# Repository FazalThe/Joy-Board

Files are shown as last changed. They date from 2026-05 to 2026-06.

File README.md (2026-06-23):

# Joy Board

A custom-built split keyboard with a built in thumb joystick on the left side, runs on zmk firmware and also supports zmk studio. The joystick is inteded to use the movements as key presses, but later is when I realised that it's really good for gaming( I don't really game, maybe thats why).

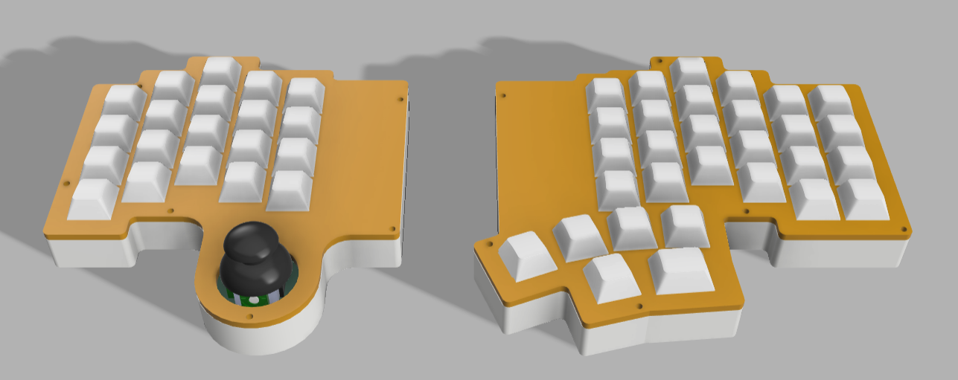
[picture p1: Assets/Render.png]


---

##  Features

-  Split Ergonomic Layout
- Thumb Joystick (Left Side)
- ZMK Studio 

---

## Schematic

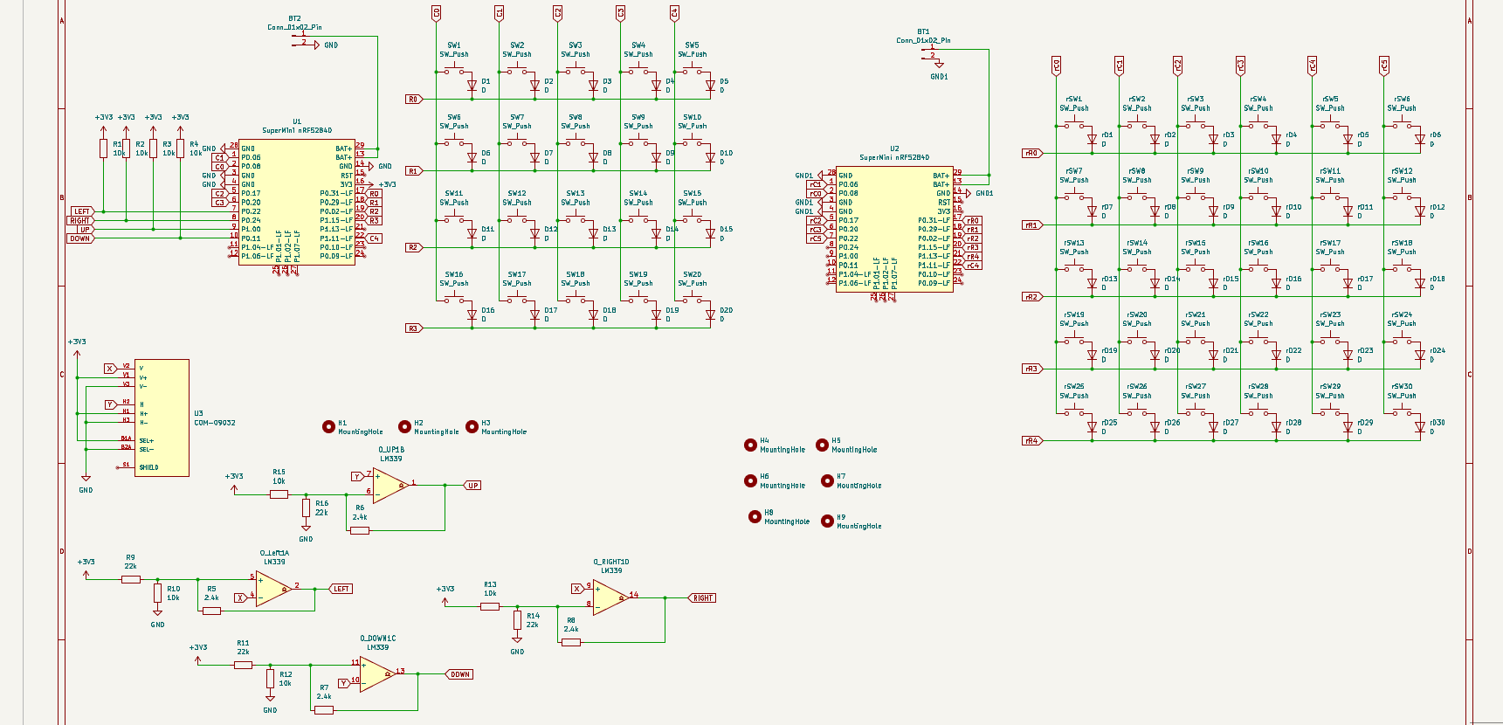
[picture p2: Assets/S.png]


---

##  PCB 

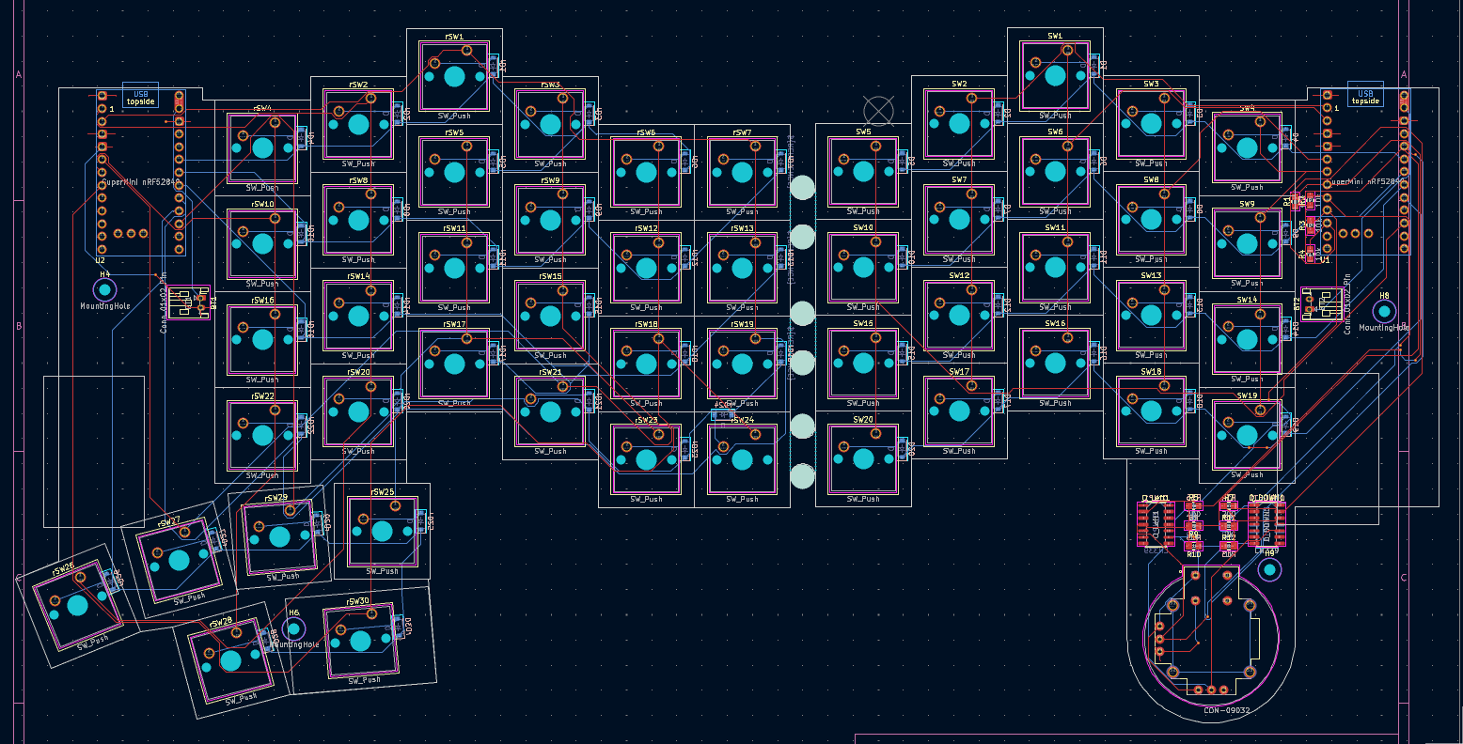
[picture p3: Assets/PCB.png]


---

## Case

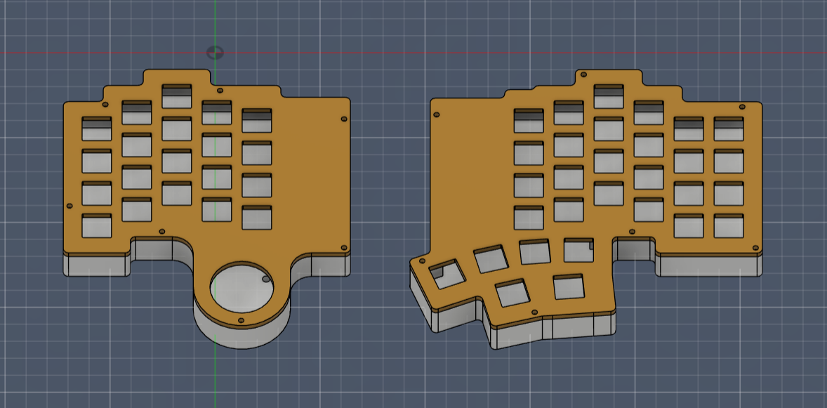
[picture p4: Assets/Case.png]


## BOM
- 2x Pro Micro nRF52840
- 50 x 1N5819 SMD Diodes
- 50 x MX-Style switches (and keycaps)
- 1  x COM-09032
- 2  x JST PH 2pin
- 8  x 10k ohm 0805 resistor
- 4  x 22k ohm 0805 resistor
- 4  x 2.4k ohm 0805 resistor
- 4  x LM339 - SOIC14
- 2  x 100-400 MaH li-po battery
- 4  x 4mm M2 Heatset insert
- 14 x 6mm M2 Heatset insert
- 4  x 6mm M2 Screws
- 14 x 8mm M2 Screws

---

## Credits

- Cherry MX keycap 3D model from [GrabCAD](https://grabcad.com/library/cherry-mx-keycaps-1).

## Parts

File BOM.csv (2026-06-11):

name | price | quantity | link | total |  | delivery and tax | whole total | USD
Cherry_MX_1u_PCB_Switch | 180 | 10 | https://stackskb.com/store/click-inc-hp-switch-pack-of-10-pre-order/ | 900
1N4148_SOD123_Diode | 20 | 5 | https://stackskb.com/store/1n4148-sod-123-smd-diode/ | 200 |  | 82
JST_PH_2pin_S2B-PH-K | 59 | 1 | https://robocraze.com/products/2-mm-pitch-jst-cable-with-connector-pack-of-10?_pos=1&_sid=52d1cda30&_ss=r | 59
LM339_SOIC14 | 12 | 5 | https://robocraze.com/products/lm339?variant=40192358514841 | 60
3.7V 400mAH Li-Po Rechargeable Battery (402020) | 114 | 2 | https://robocraze.com/products/witty-fox-3-7v-400mah-rechargeable-lipo-battery-1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 | 228
Resistor_10k_0805 | 10 | 1 | https://quartzcomponents.com/products/10k-ohm-103-5-smd-resistor-0805-pack-of-20-pieces?variant=43451349729514 | 10 | min order | 49
Resistor_2.4k_0805 | 10 | 1 | https://quartzcomponents.com/products/1-1k-ohm-1k1-1-smd-resistor-0805-pack-of-20-pieces-copy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 | 10 | min order
Resistor_22k_0805 | 8 | 1 | https://quartzcomponents.com/products/22k-ohm-223-5-smd-resistor-0805-pack-of-20-pieces?variant=43515941421290 | 8 | min order | 64.04
Promicro NRF52840 | 758 | 2 | https://robu.in/product/promicro-nrf52840-development-board/ | 1516
Thumb_Joystick_COM-09032 | 86 | 1 | https://arrowtechcart.com/products/thumb-joystick-switch-xy-dual-axis-4-way-direction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 | 86 |  | 89
M2 screw 6mm | 2 | 6 | https://onlyscrews.in/products/m2-x-6mm-phillips-pan-head-ss-304-screw?variant=49225893839161 | 12
M2 screw 8mm | 1.8 | 17 | https://onlyscrews.in/products/m2-x-8mm-phillips-csk-ss-304-screw-dia-2mm-length-8mm?variant=51155018514745 | 30.6
M2 heatset 4mm | 2 | 5 | https://onlyscrews.in/products/m2-x-4mm-brass-threaded-inserts?variant=49423172829497 | 10
M2 heatset 6mm | 1.4 | 17 | https://onlyscrews.in/products/m2-x-6mm-brass-threaded-inserts?variant=49423242101049 | 40.8 |  | 70.17
 |  |  |  | 3170.4 |  | 354.21 | 3524.61 | 38
PCB | 13$ |  |  |  |  |  |  | 13
USD Final total |  |  |  |  |  |  |  | 41

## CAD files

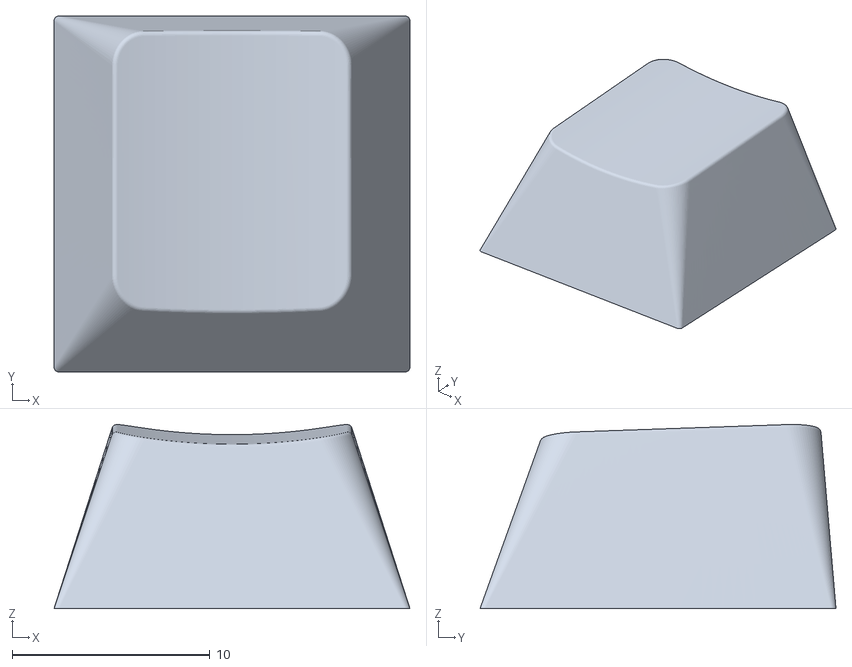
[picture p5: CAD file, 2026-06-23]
3D/Key Cap 1u.stl
18.0 x 18.0 x 9.31

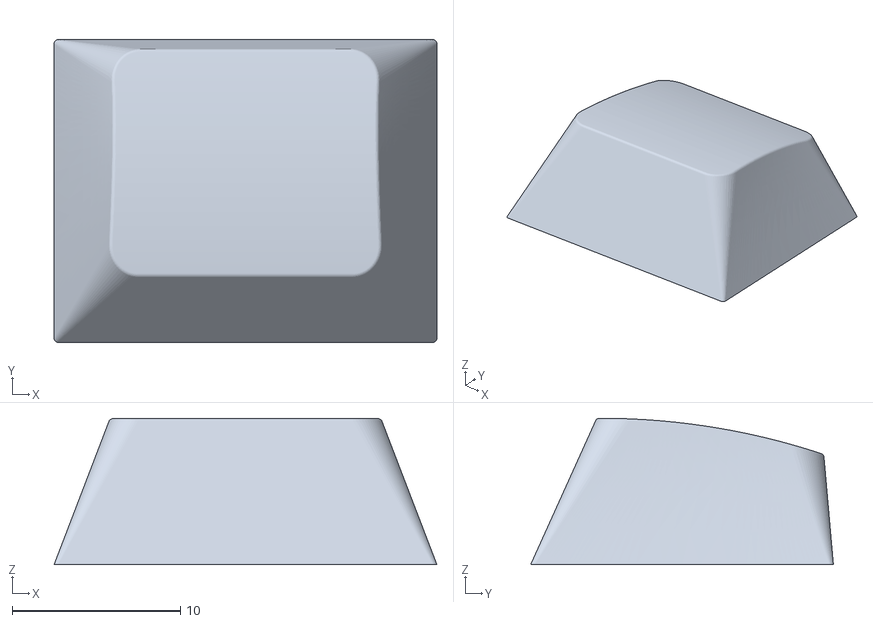
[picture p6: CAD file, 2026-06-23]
3D/Key Cap 1.5u.stl
22.8 x 18.0 x 8.70

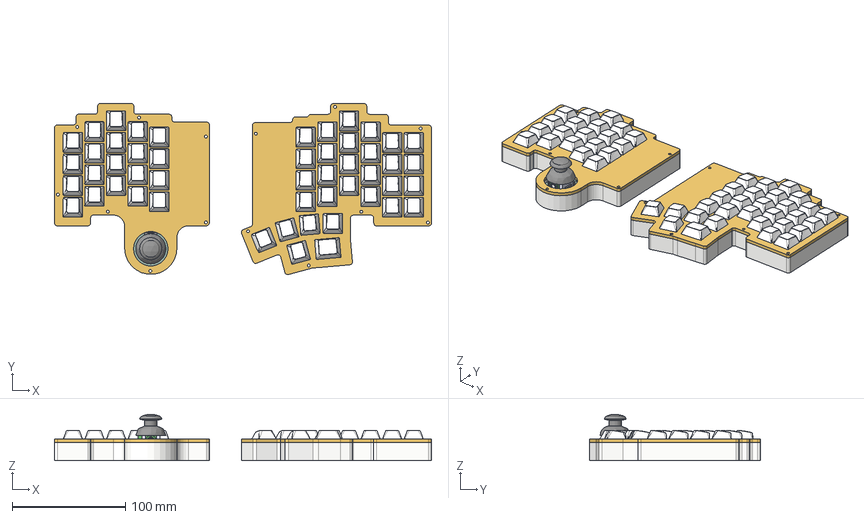
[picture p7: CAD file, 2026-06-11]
3D/STEP.stp
332.9 x 151.2 x 41.0 mm
Bottom x 30
Pulsador x 30
Top x 30
Pieza5^Cherry MX x 30
Pin1 x 30
Pin2 x 30
Led 3mm_trans x 30
nw 1 x 29
JST_PH_S2B-PH-K_1x02_P2.00mm_Horizontal
nice!nano v1.0
LED_0603_1608Metric_ON v1
LED_0603_1608Metric_ON v1(Mirror)
Crystal Oscillator v3
Crystal Oscillator v3 (1)
usb4520-03-0-a v1
C0201 v1 x 21
C0402 v1 x 8
0603 v1 x 2
C0201 v1_1 x 7
D_SOD-123 x 30
Joy Board_PCB
Bottom_1 x 20
Pulsador_1 x 20
Top_1 x 20
Pieza5^Cherry MX_1 x 20
Pin1_1 x 20
Pin2_1 x 20
Led 3mm_trans_1 x 20
nw 1_1 x 20
R_0805_2012Metric x 16
nice!nano v1.0_1
LED_0603_1608Metric_ON v1_1
LED_0603_1608Metric_ON v1(Mirror)_1
Crystal Oscillator v3_1
Crystal Oscillator v3 (1)_1
usb4520-03-0-a v1_1
C0201 v1_2 x 21
C0402 v1_1 x 8
0603 v1_1 x 2
C0201 v1_3 x 7
JST_PH_S2B-PH-K_1x02_P2.00mm_Horizontal_1
SOIC-14_3.9x8.7mm_P1.27mm x 4
COM-09032
D_SOD-123_1 x 20
Joy Board_PCB_1

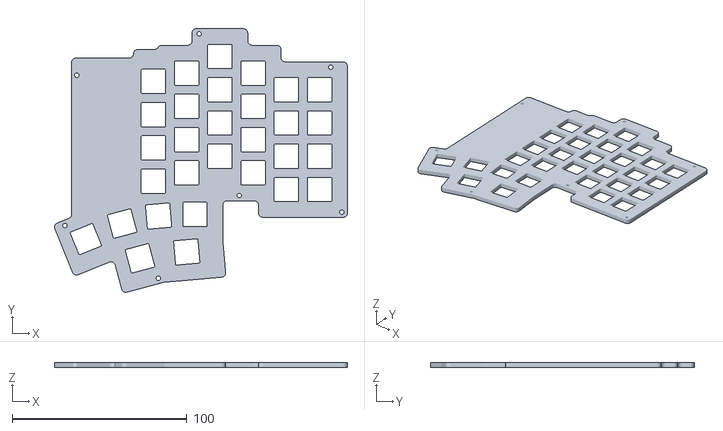
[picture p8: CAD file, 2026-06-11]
3D/Right Lid.stl
167.9 x 151.1 x 3.00

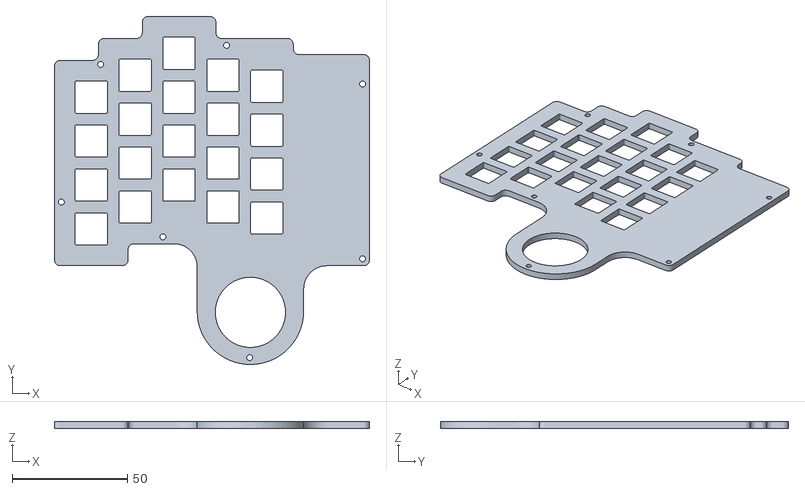
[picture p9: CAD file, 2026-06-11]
3D/Left Lid.stl
136.7 x 151.0 x 3.00

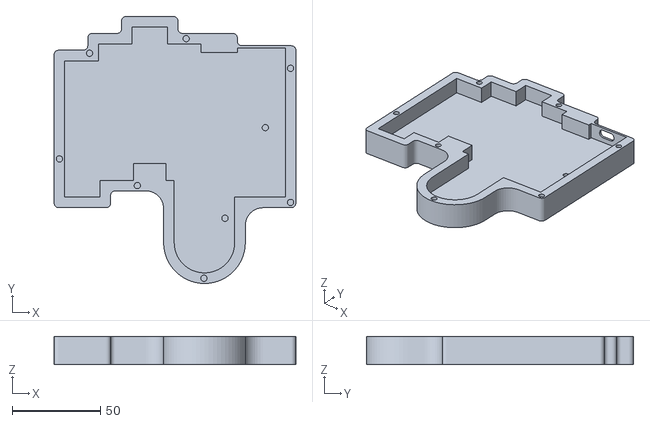
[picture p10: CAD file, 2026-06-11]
3D/Left Case.stl
136.7 x 151.0 x 16.0

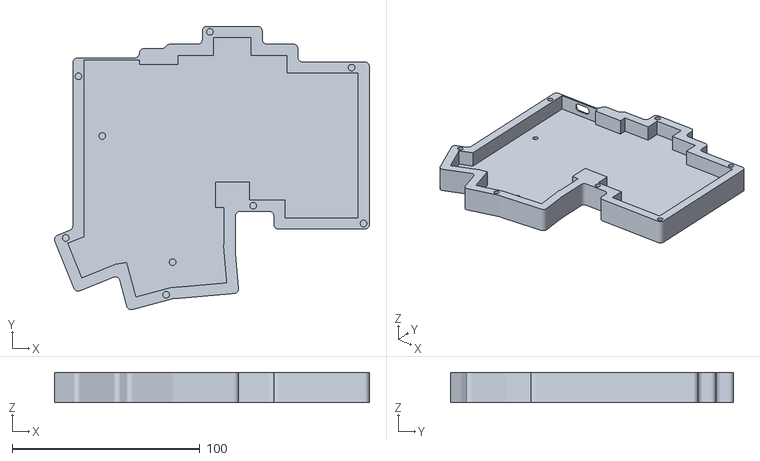
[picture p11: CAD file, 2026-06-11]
3D/Right Case.stl
167.9 x 151.1 x 16.0

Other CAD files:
3D/Left Source File.f3z
3D/Right Source File.f3z

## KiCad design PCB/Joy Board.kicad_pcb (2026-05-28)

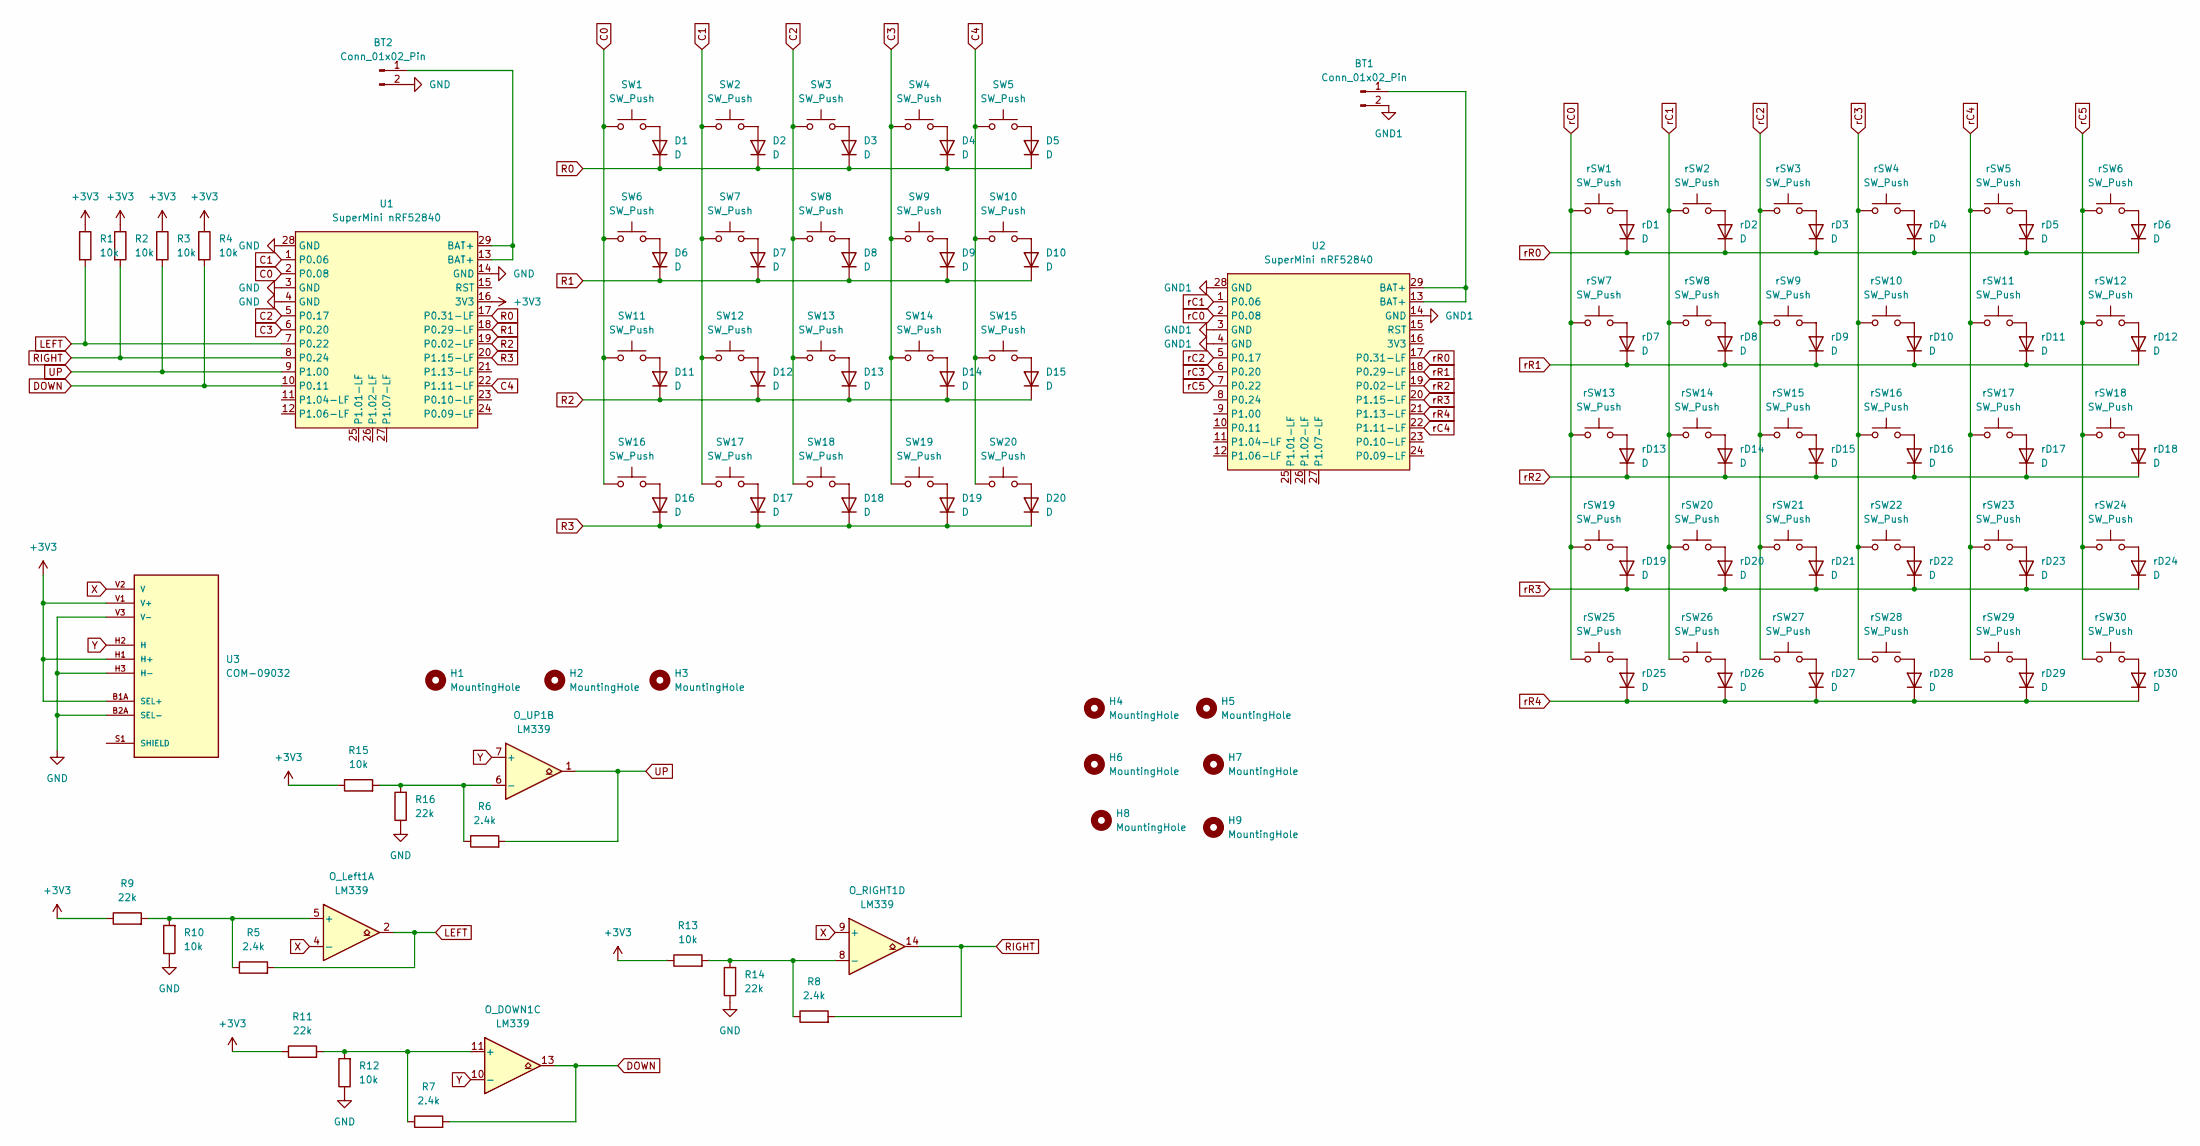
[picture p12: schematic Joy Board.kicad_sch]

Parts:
BT1, BT2: Conn_01x02_Pin; JST_PH_S2B-PH-K_1x02_P2.00mm_Horizontal
D1, D2, D3, D4, D5, D6, D7, D8, D9, D10, D11, D12, D13, D14, D15, D16, D17, D18, D19, D20: D; D_SOD-123
H1, H2, H3: MountingHole; mouse-bite-5mm-slot
H4, H5, H6, H7, H8, H9: MountingHole; MountingHole_2.2mm_M2
O_DOWN1: LM339; SOIC-14_3.9x8.7mm_P1.27mm
O_Left1: LM339; SOIC-14_3.9x8.7mm_P1.27mm
O_RIGHT1: LM339; SOIC-14_3.9x8.7mm_P1.27mm
O_UP1: LM339; SOIC-14_3.9x8.7mm_P1.27mm
R1, R2, R3, R4, R10, R12, R13, R15: 10k; R_0805_2012Metric_Pad1.20x1.40mm_HandSolder
R5, R6, R7, R8: 2.4k; R_0805_2012Metric_Pad1.20x1.40mm_HandSolder
R9, R11, R14, R16: 22k; R_0805_2012Metric_Pad1.20x1.40mm_HandSolder
SW1, SW2, SW3, SW4, SW5, SW6, SW7, SW8, SW9, SW10, SW11, SW12, SW13, SW14, SW15, SW16, SW17, SW18, SW19, SW20: SW_Push; SW_Cherry_MX_1.00u_PCB_3d
U1, U2: SuperMini nRF52840; SuperMini_nRF52840_AH_USBup
U3: COM-09032; XDCR_COM-09032; PARTREV N/A
rD1, rD2, rD3, rD4, rD5, rD6, rD7, rD8, rD9, rD10, rD11, rD12, rD13, rD14, rD15, rD16, rD17, rD18, rD19, rD20, rD21, rD22, rD23, rD24, rD25, rD26, rD27, rD28, rD29, rD30: D; D_SOD-123
rSW1, rSW2, rSW3, rSW4, rSW5, rSW6, rSW7, rSW8, rSW9, rSW10, rSW11, rSW12, rSW13, rSW14, rSW15, rSW16, rSW17, rSW18, rSW19, rSW20, rSW21, rSW22, rSW23, rSW24, rSW25, rSW26, rSW27, rSW28, rSW29: SW_Push; SW_Cherry_MX_1.00u_PCB_3d
rSW30: SW_Push; SW_Cherry_MX_1.50u_PCB

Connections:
+3V3: R1.1, R2.1, R3.1, R4.1, R9.1, R11.1, R13.1, R15.1, U1.16 (3V3), U3.B1A (SEL+), U3.H1 (H+), U3.V1 (V+)
C0: SW1.1, SW6.1, SW11.1, SW16.1, U1.2 (P0.08)
C1: SW2.1, SW7.1, SW12.1, SW17.1, U1.1 (P0.06)
C2: SW3.1, SW8.1, SW13.1, SW18.1, U1.5 (P0.17)
C3: SW4.1, SW9.1, SW14.1, SW19.1, U1.6 (P0.20)
C4: SW5.1, SW10.1, SW15.1, SW20.1, U1.22 (P1.11-LF)
DOWN: O_DOWN1.13, R4.2, R7.2, U1.10 (P0.11)
GND: BT2.2, R10.1, R12.1, R14.1, R16.1, U1.3 (GND), U1.4 (GND), U1.14 (GND), U1.28 (GND), U3.B2A (SEL-), U3.H3 (H-), U3.V3 (V-)
GND1: BT1.2, U2.3 (GND), U2.4 (GND), U2.14 (GND), U2.28 (GND)
LEFT: O_Left1.2, R1.2, R5.2, U1.7 (P0.22)
unnamed: BT1.1, U2.13 (BAT+), U2.29 (BAT+)
unnamed: BT2.1, U1.13 (BAT+), U1.29 (BAT+)
unnamed: D1.2 (A), SW1.2
unnamed: D2.2 (A), SW2.2
unnamed: D3.2 (A), SW3.2
unnamed: D4.2 (A), SW4.2
unnamed: D5.2 (A), SW5.2
unnamed: D6.2 (A), SW6.2
unnamed: D7.2 (A), SW7.2
unnamed: D8.2 (A), SW8.2
unnamed: D9.2 (A), SW9.2
unnamed: D10.2 (A), SW10.2
unnamed: D11.2 (A), SW11.2
unnamed: D12.2 (A), SW12.2
unnamed: D13.2 (A), SW13.2
unnamed: D14.2 (A), SW14.2
unnamed: D15.2 (A), SW15.2
unnamed: D16.2 (A), SW16.2
unnamed: D17.2 (A), SW17.2
unnamed: D18.2 (A), SW18.2
unnamed: D19.2 (A), SW19.2
unnamed: D20.2 (A), SW20.2
unnamed: O_DOWN1.11 (+), R7.1, R11.2, R12.2
unnamed: O_Left1.5 (+), R5.1, R9.2, R10.2
unnamed: O_RIGHT1.8 (-), R8.1, R13.2, R14.2
unnamed: O_UP1.6 (-), R6.1, R15.2, R16.2
unnamed: U3.S1 (SHIELD), U3.S2 (SHIELD), U3.S3 (SHIELD), U3.S4 (SHIELD)
unnamed: rD1.2 (A), rSW1.2
unnamed: rD2.2 (A), rSW2.2
unnamed: rD3.2 (A), rSW3.2
unnamed: rD4.2 (A), rSW4.2
unnamed: rD5.2 (A), rSW5.2
unnamed: rD6.2 (A), rSW6.2
unnamed: rD7.2 (A), rSW7.2
unnamed: rD8.2 (A), rSW8.2
unnamed: rD9.2 (A), rSW9.2
unnamed: rD10.2 (A), rSW10.2
unnamed: rD11.2 (A), rSW11.2
unnamed: rD12.2 (A), rSW12.2
unnamed: rD13.2 (A), rSW13.2
unnamed: rD14.2 (A), rSW14.2
unnamed: rD15.2 (A), rSW15.2
unnamed: rD16.2 (A), rSW16.2
unnamed: rD17.2 (A), rSW17.2
unnamed: rD18.2 (A), rSW18.2
unnamed: rD19.2 (A), rSW19.2
unnamed: rD20.2 (A), rSW20.2
unnamed: rD21.2 (A), rSW21.2
unnamed: rD22.2 (A), rSW22.2
unnamed: rD23.2 (A), rSW23.2
unnamed: rD24.2 (A), rSW24.2
unnamed: rD25.2 (A), rSW25.2
unnamed: rD26.2 (A), rSW26.2
unnamed: rD27.2 (A), rSW27.2
unnamed: rD28.2 (A), rSW28.2
unnamed: rD29.2 (A), rSW29.2
unnamed: rD30.2 (A), rSW30.2
R0: D1.1 (K), D2.1 (K), D3.1 (K), D4.1 (K), D5.1 (K), U1.17 (P0.31-LF)
R1: D6.1 (K), D7.1 (K), D8.1 (K), D9.1 (K), D10.1 (K), U1.18 (P0.29-LF)
R2: D11.1 (K), D12.1 (K), D13.1 (K), D14.1 (K), D15.1 (K), U1.19 (P0.02-LF)
R3: D16.1 (K), D17.1 (K), D18.1 (K), D19.1 (K), D20.1 (K), U1.20 (P1.15-LF)
RIGHT: O_RIGHT1.14, R2.2, R8.2, U1.8 (P0.24)
UP: O_UP1.1, R3.2, R6.2, U1.9 (P1.00)
X: O_Left1.4 (-), O_RIGHT1.9 (+), U3.V2 (V)
Y: O_DOWN1.10 (-), O_UP1.7 (+), U3.H2 (H)
rC0: U2.2 (P0.08), rSW1.1, rSW7.1, rSW13.1, rSW19.1, rSW25.1
rC1: U2.1 (P0.06), rSW2.1, rSW8.1, rSW14.1, rSW20.1, rSW26.1
rC2: U2.5 (P0.17), rSW3.1, rSW9.1, rSW15.1, rSW21.1, rSW27.1
rC3: U2.6 (P0.20), rSW4.1, rSW10.1, rSW16.1, rSW22.1, rSW28.1
rC4: U2.22 (P1.11-LF), rSW5.1, rSW11.1, rSW17.1, rSW23.1, rSW29.1
rC5: U2.7 (P0.22), rSW6.1, rSW12.1, rSW18.1, rSW24.1, rSW30.1
rR0: U2.17 (P0.31-LF), rD1.1 (K), rD2.1 (K), rD3.1 (K), rD4.1 (K), rD5.1 (K), rD6.1 (K)
rR1: U2.18 (P0.29-LF), rD7.1 (K), rD8.1 (K), rD9.1 (K), rD10.1 (K), rD11.1 (K), rD12.1 (K)
rR2: U2.19 (P0.02-LF), rD13.1 (K), rD14.1 (K), rD15.1 (K), rD16.1 (K), rD17.1 (K), rD18.1 (K)
rR3: U2.20 (P1.15-LF), rD19.1 (K), rD20.1 (K), rD21.1 (K), rD22.1 (K), rD23.1 (K), rD24.1 (K)
rR4: U2.21 (P1.13-LF), rD25.1 (K), rD26.1 (K), rD27.1 (K), rD28.1 (K), rD29.1 (K), rD30.1 (K)

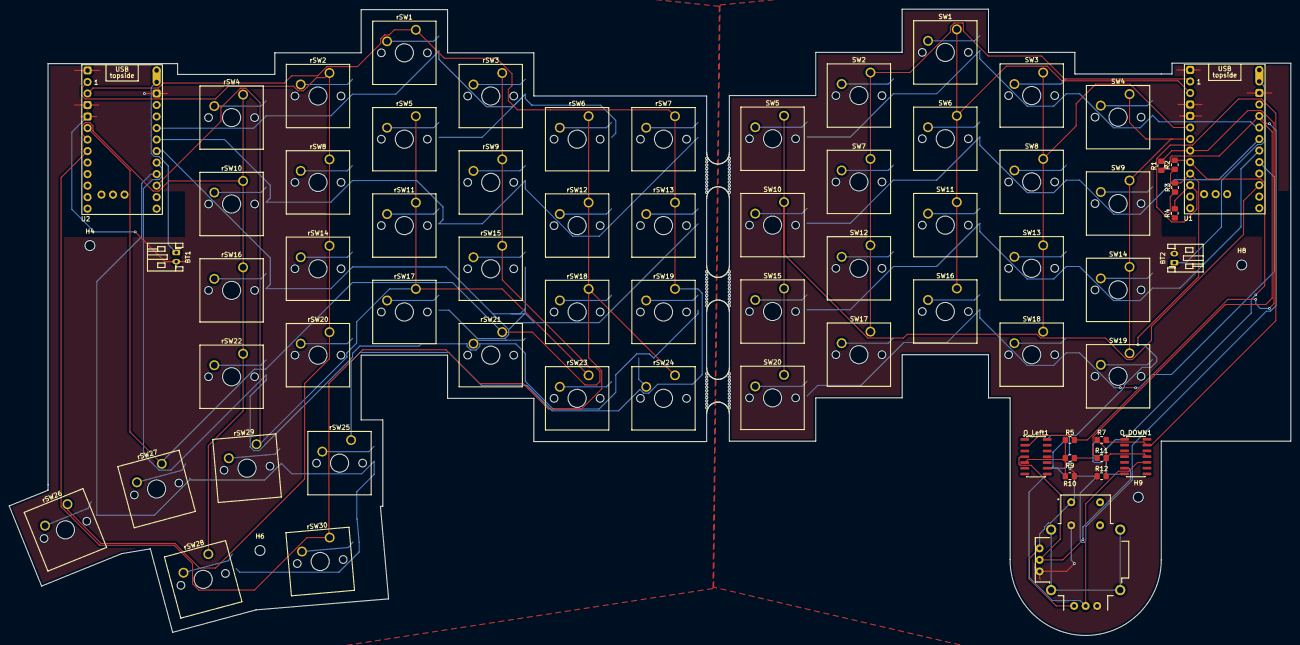
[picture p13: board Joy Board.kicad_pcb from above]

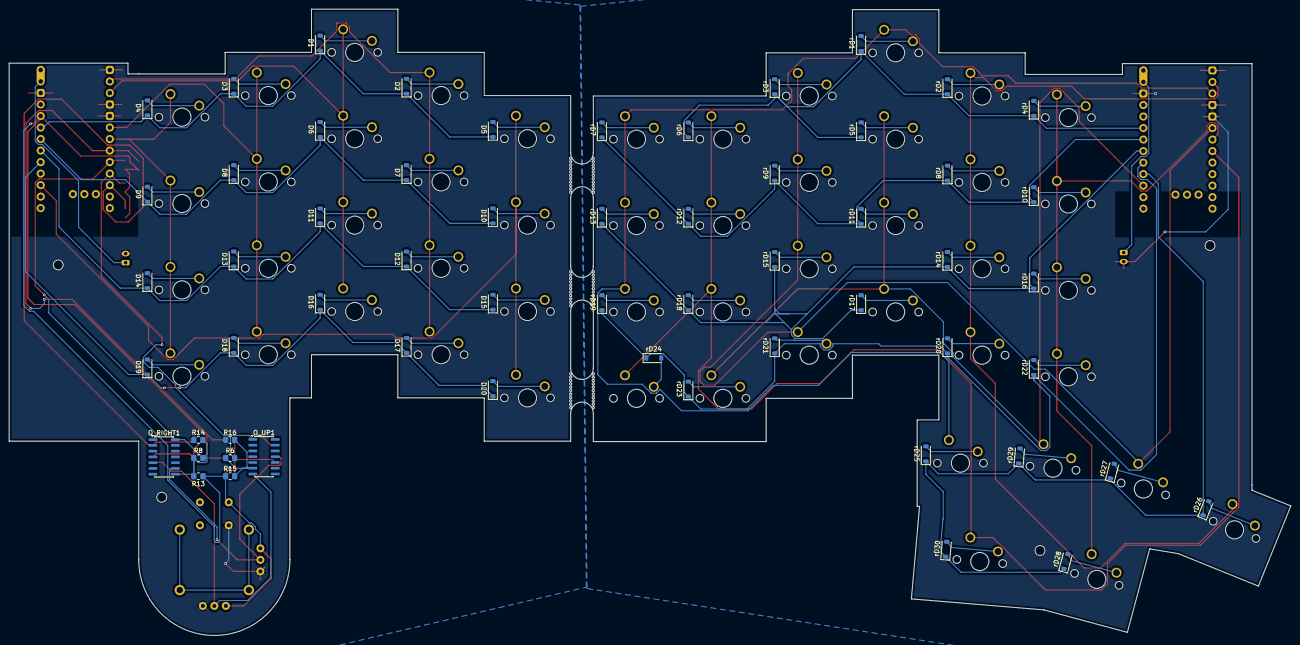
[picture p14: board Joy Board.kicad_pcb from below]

Board: 2 copper layers, 282.6 x 138.1 mm, 132 parts (58 on the bottom side), 86 nets.

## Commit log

2026-03-31 Create README.md for Joy Board project
    Added initial README with project details and features.
2026-05-23 Revise README with detailed description and BOM
    Updated the README to enhance the description of the Joy Board and added a BOM section.
2026-05-24 really done
    [Left Case.stl, Right Case.stl]
2026-05-27 firmware done and updated to latest pcb
    [Joy Board.csv, Joy Board.kicad_pcb, Joy Board.kicad_sch]
2026-05-28 pcb missing fixed
    [Joy Board.csv, Joy Board.kicad_pcb]
2026-05-28 BOM fix
    [BOM.csv]
2026-06-11 1st Re-submit
    [BOM.csv, JB Left_.f3z, JB Right.f3z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]
2026-06-11 Add schematic section to README
